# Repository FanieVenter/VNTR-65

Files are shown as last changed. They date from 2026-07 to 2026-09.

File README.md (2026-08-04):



# VNTR-65

A custom, over-engineered 65% keyboard featuring an RP2350 MCU, a hall effect key matrix, an analog slide potentiometer, and an OLED display. Built for daily use thanks to Hack Club.

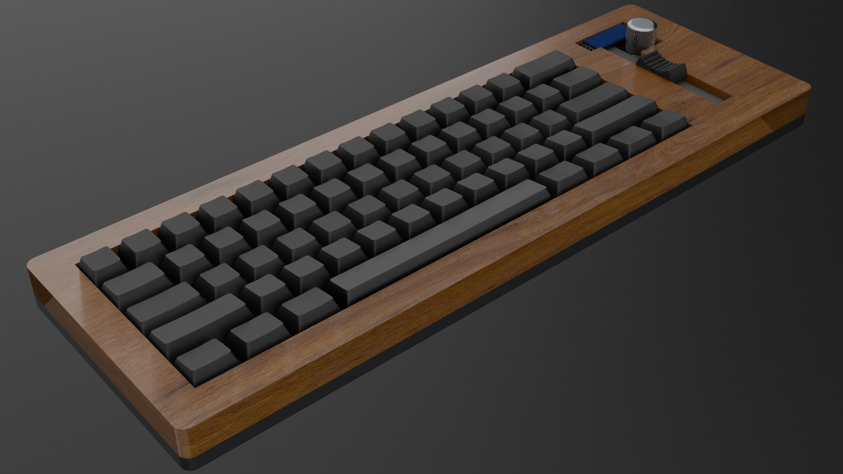
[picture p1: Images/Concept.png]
Concept Image


## Why I decided to make this keyboard.
I wanted to build a nice keyboard that I could use every day at school while knowing it won't break, I also wanted to make a keyboard that used hall effect switches to allow for analog inputs in racing ganes like Assetto Corsa and giving me a more challenging and fun experience designing it.

## How to use it.
To use this keyboard you will need to either download the production files for JLCPCB or create your own by exporting it them from Kicad. You will then need to place a order for the PCB using the productions files at your chosen pcb manufacturer. After you have received the PCB you will need to solder all the components onto the PCB and then flash the firmware onto the RP2350. While this is happening you can either 3d print the case or get it milled out of aluminum and wood. After you have the case and the PCB ready you can then assemble the keyboard and upload the firmware to the RP2350 and then you can use it. 

## What I learnt with this project.
I learn't how to design a keyboard from scratch using Kicad for the pcb. I also learn't how to use onshape after deciding to swap to it from Freecad a little bit because the projects says to have it in onshape but mostly as I had realised after 2 years of FreeCAD use that it wasn't powerful enough for me. I learn't how to take a raw wood texture file and make it look like a satin polyeuranted finished piece of wood in blender.
# Important.
The cost of the pcba has gone down since I submitted the project for review. For updated pricing and screenshot check the [BOM](BOM.pdf).

## Onshape Link
Onshape link for the [Case](https://cad.onshape.com/documents/299d1cd18e1c0fa7ad37c188/w/39af968ec4536d8e3dda6814/e/b83c5326b9acf81a68bd5a35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).

## Files
- [Journal](Journal.md) Journal of this project.
- [PCB Files](Hardware/PCB) Kicad files for the keyboard.
- [Production Files](Hardware/PCB/production) Production files for this project.
- [3D Files](Hardware/3D%20Models) 3D models used in this project as well as where the blender file is.
- [Gallery](Gallery.md) Images of the project and renders of the keyboard.
- [BOM (PDF)](BOM.pdf) Bill of materials.
- [BOM (CSV)](BOM.csv) Bill of materials in CSV format.

## Schematic-Main
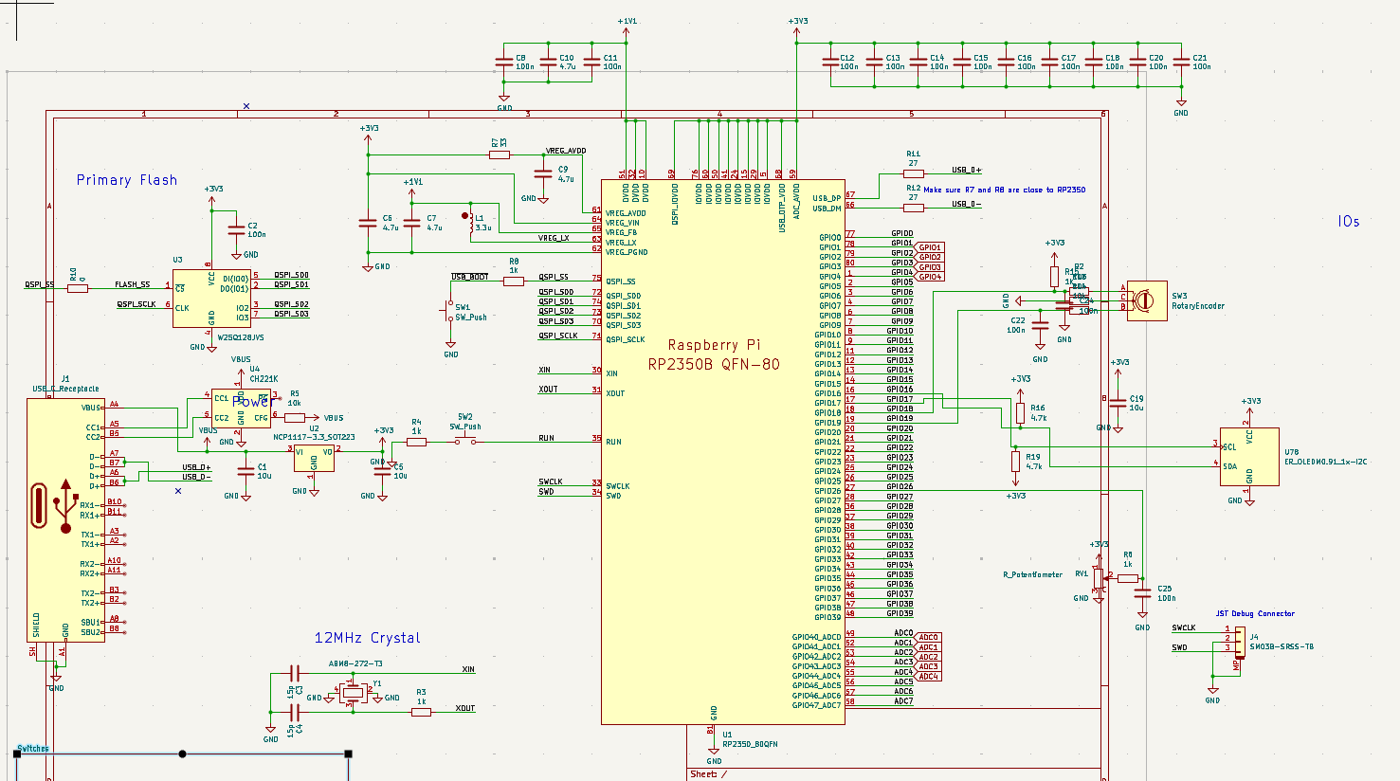
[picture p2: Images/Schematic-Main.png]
Schematic-Main


*Main schematic.*  

## Schematic-Switch
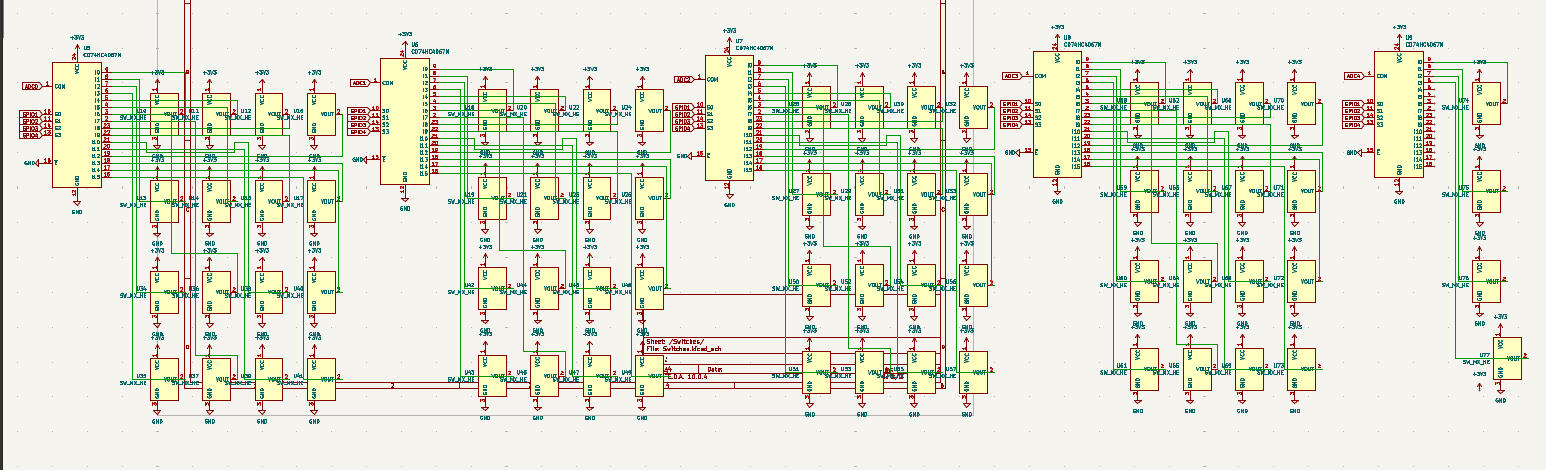
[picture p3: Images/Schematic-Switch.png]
Schematic-Switch


*Hall effect switch matrix.*

## PCB Photos
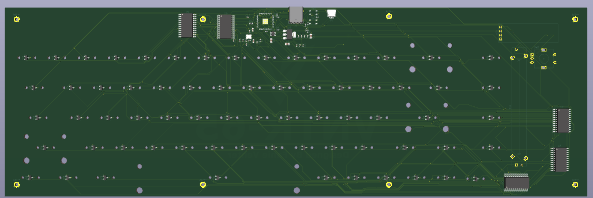
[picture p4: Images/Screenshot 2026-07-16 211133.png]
PCB Front

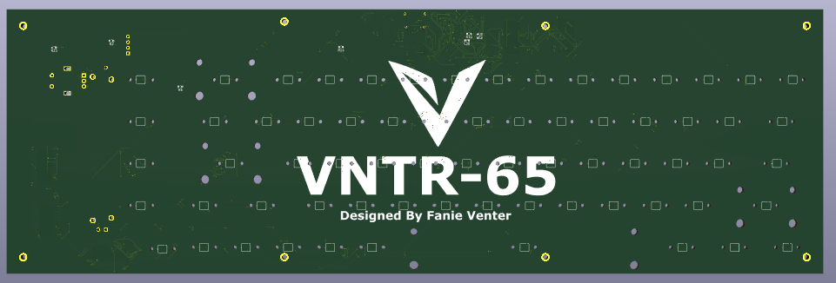
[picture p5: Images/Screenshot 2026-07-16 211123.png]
PCB Back (with silkscreen)


*Front and back of the PCB — the back has the silkscreen applied.*

## Wiring
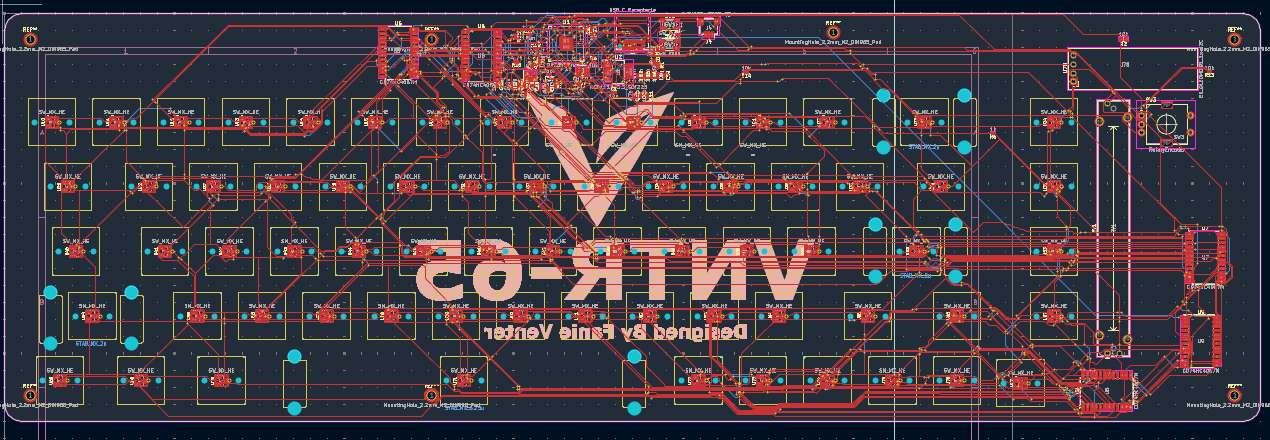
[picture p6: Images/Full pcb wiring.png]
Full PCB wiring


*Full PCB wiring across all copper layers.*

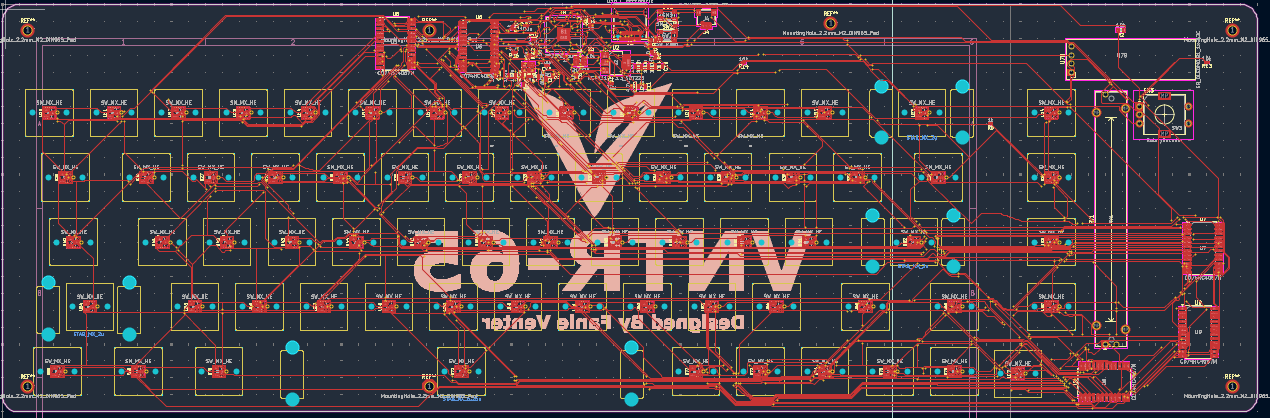
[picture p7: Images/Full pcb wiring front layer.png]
Full PCB wiring front layer


*Full PCB wiring on the front copper layer.*

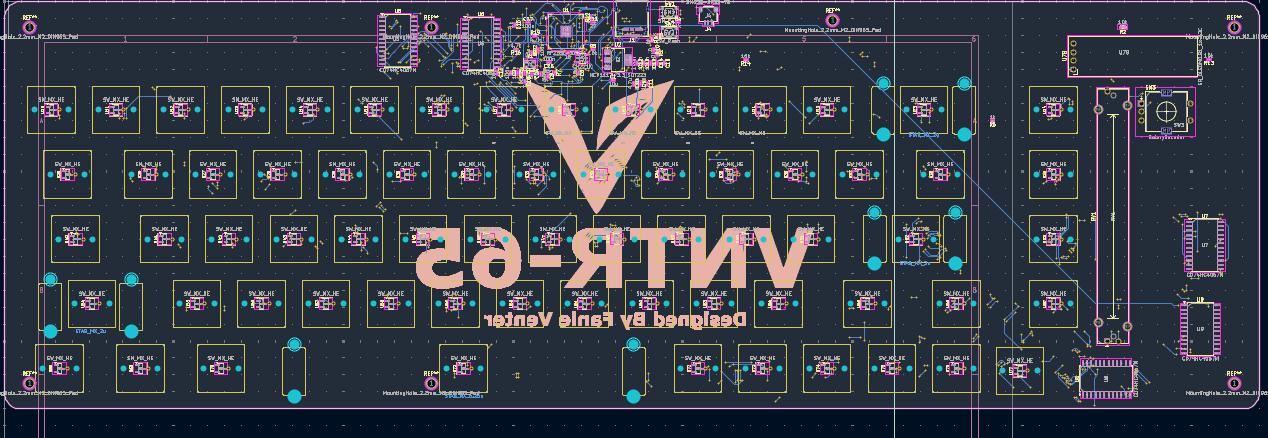
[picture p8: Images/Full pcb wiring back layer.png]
Full PCB wiring back layer


*Full PCB wiring on the back copper layer.*

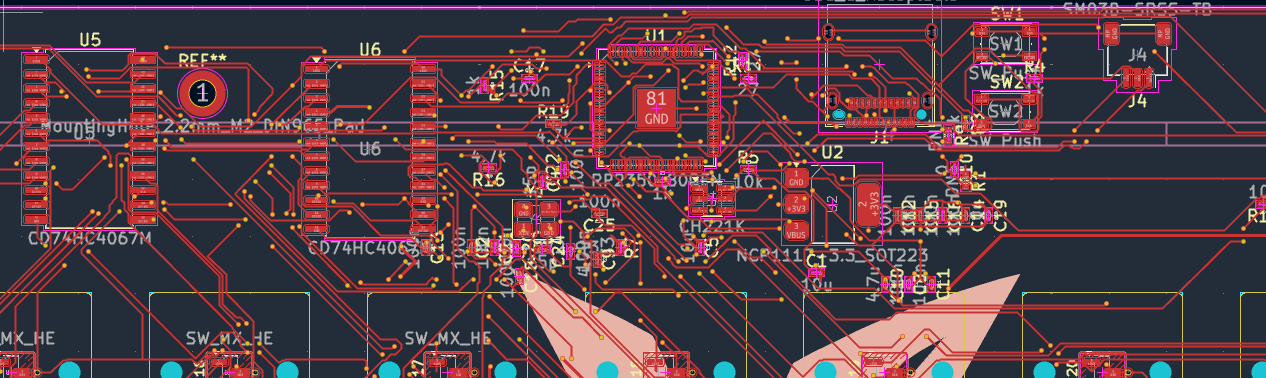
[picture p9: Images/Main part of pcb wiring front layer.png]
Main part of PCB wiring front layer


*Main section wiring on the front copper layer.*

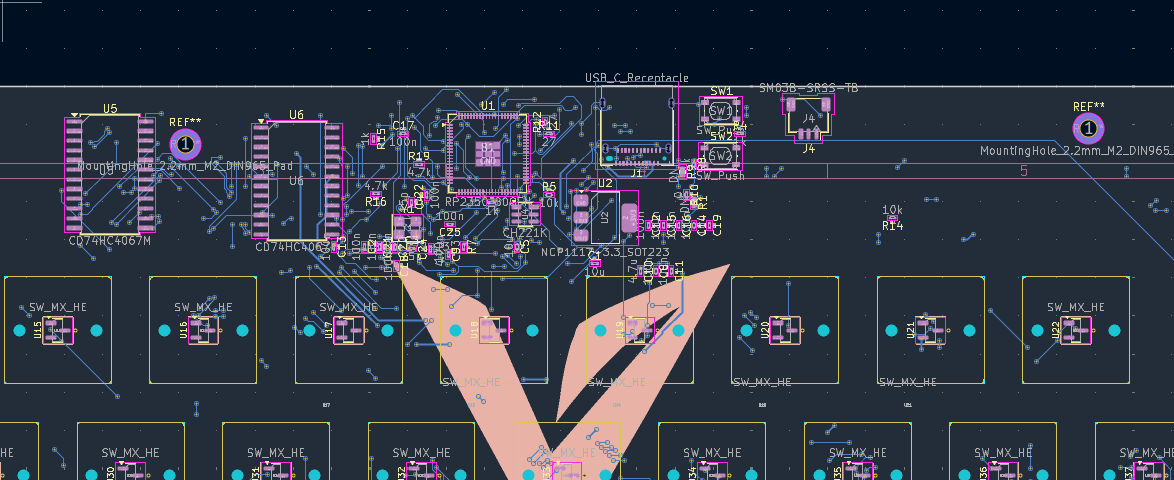
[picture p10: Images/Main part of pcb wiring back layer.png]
Main part of PCB wiring back layer


*Main section wiring on the back copper layer.*

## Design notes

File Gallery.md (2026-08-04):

# Gallery

## 2026-07-09

Keyboard Layout

*SVG layout showing the initial key positioning.*

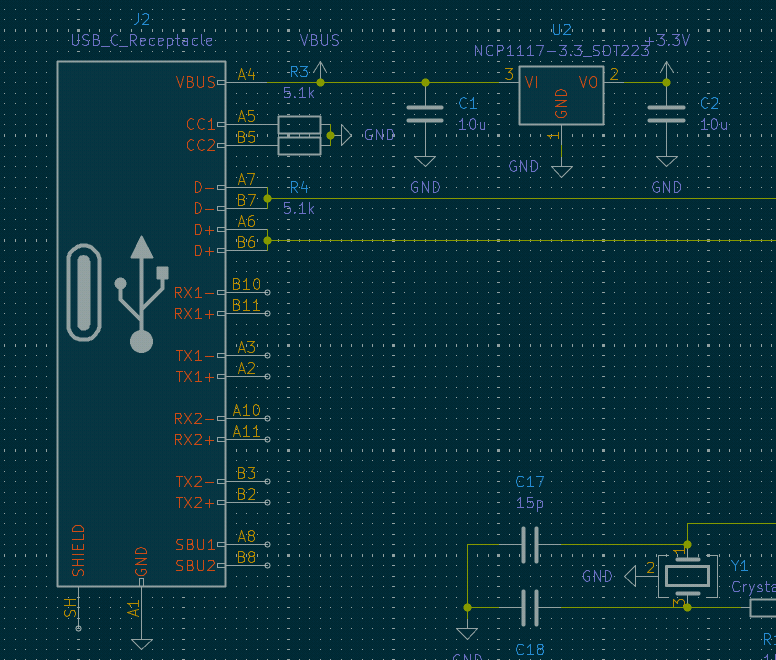
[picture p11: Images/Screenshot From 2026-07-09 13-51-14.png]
KiCad schematic at 13:51


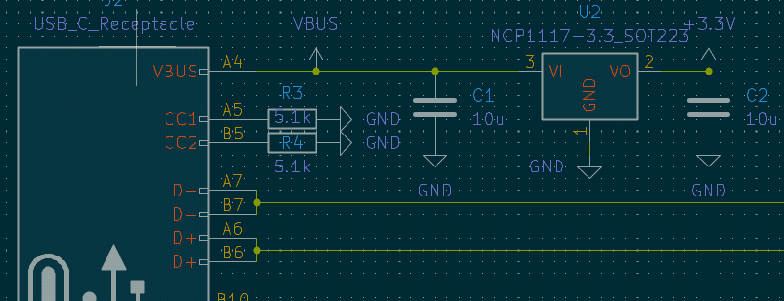
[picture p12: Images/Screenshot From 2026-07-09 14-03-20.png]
KiCad schematic at 14:03


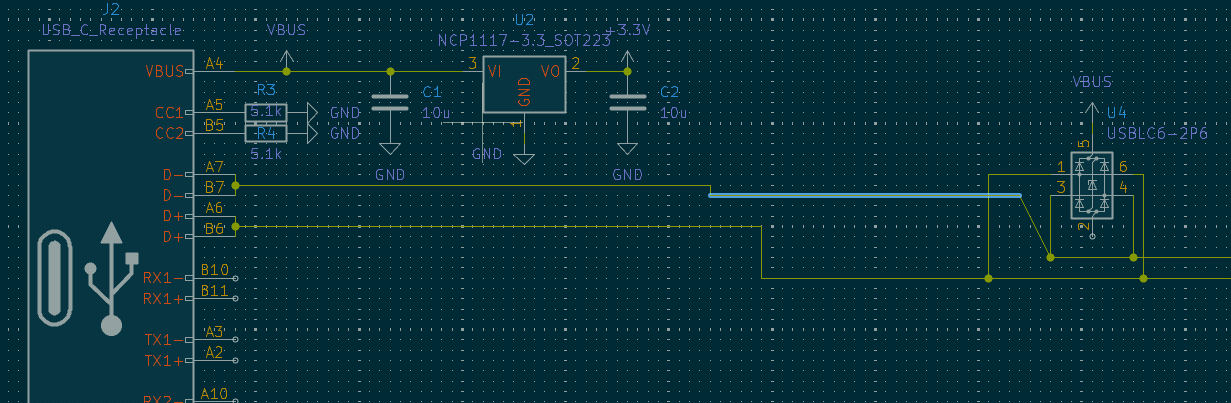
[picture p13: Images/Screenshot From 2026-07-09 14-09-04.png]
KiCad schematic at 14:09


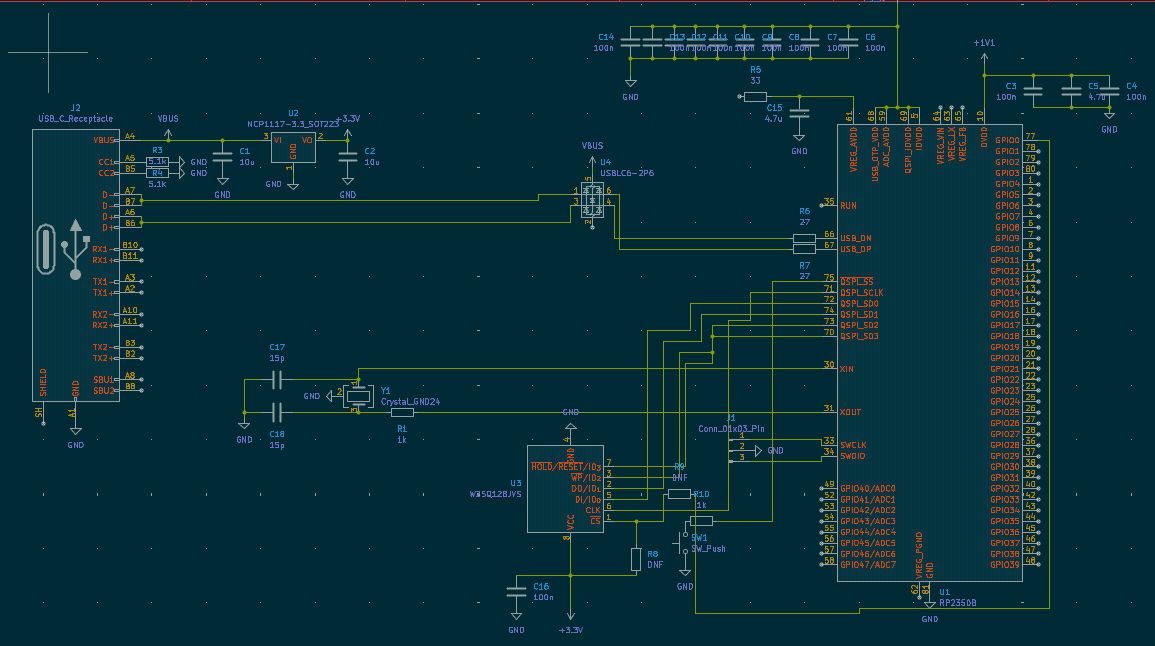
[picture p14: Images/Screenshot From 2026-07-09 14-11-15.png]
KiCad schematic at 14:11


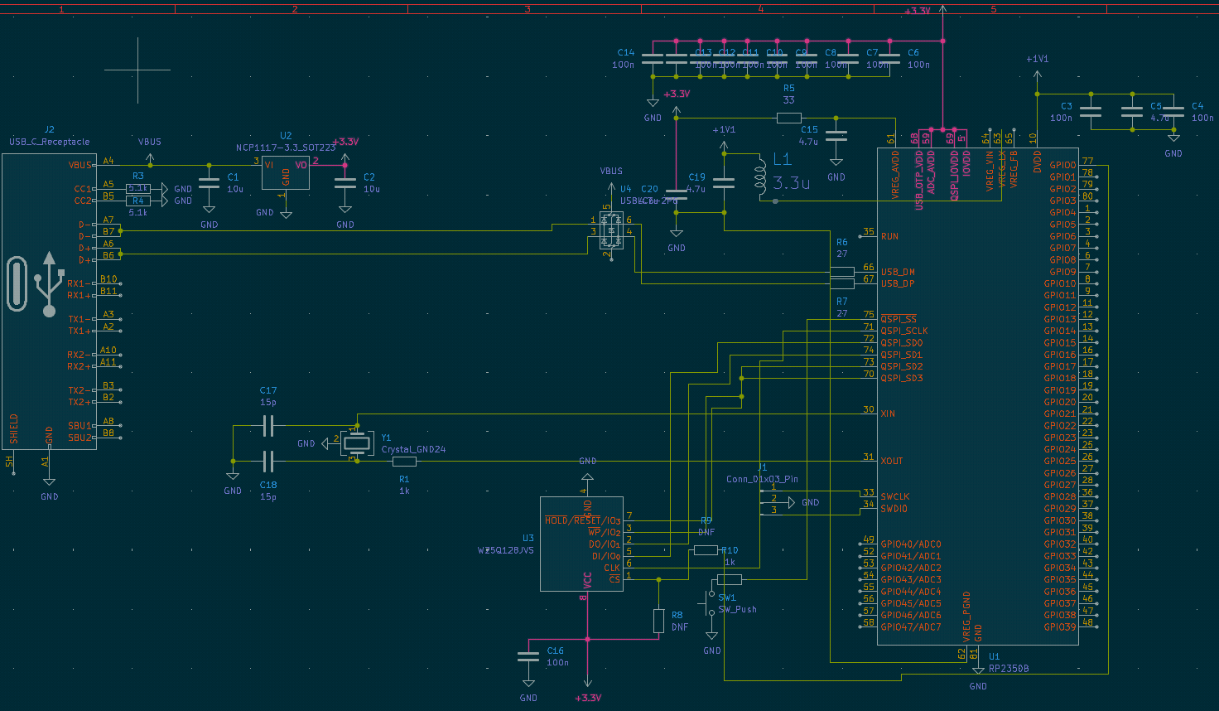
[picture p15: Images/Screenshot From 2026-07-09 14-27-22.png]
KiCad schematic at 14:27


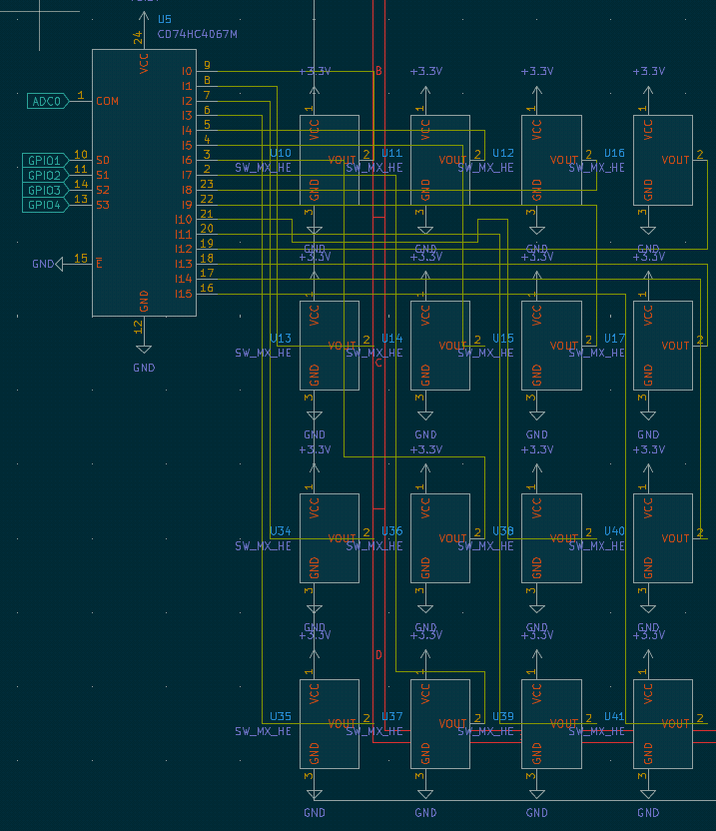
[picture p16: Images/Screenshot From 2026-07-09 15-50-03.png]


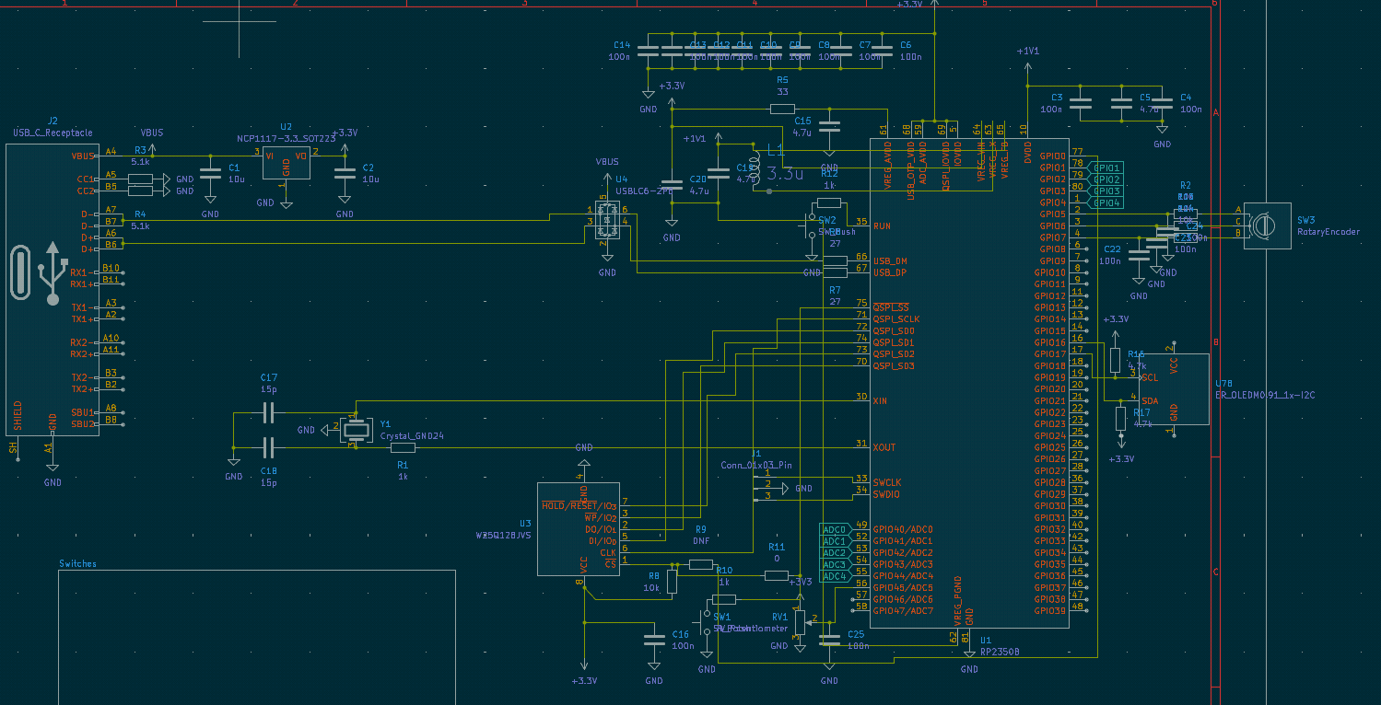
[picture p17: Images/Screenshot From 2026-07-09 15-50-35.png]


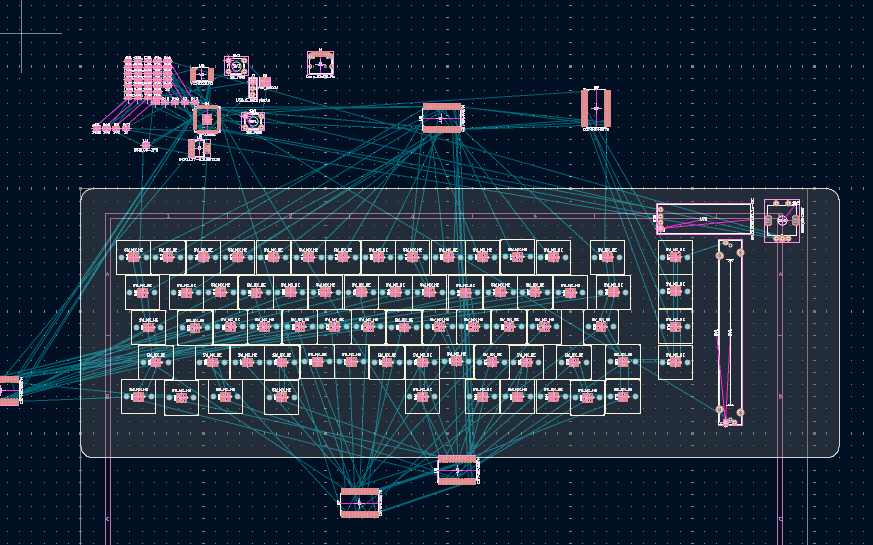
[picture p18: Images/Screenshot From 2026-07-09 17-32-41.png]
PCB layout at 17:32


*Schematic and PCB design progress from 9 July.*

## 2026-07-10

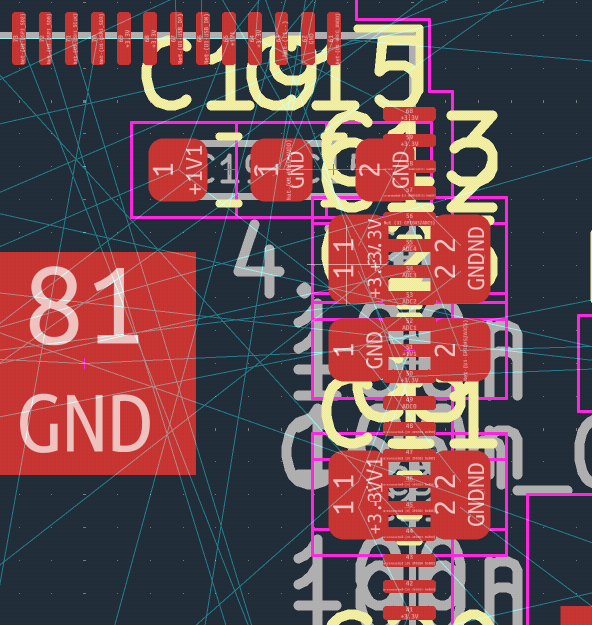
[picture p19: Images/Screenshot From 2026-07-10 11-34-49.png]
PCB routing at 11:34


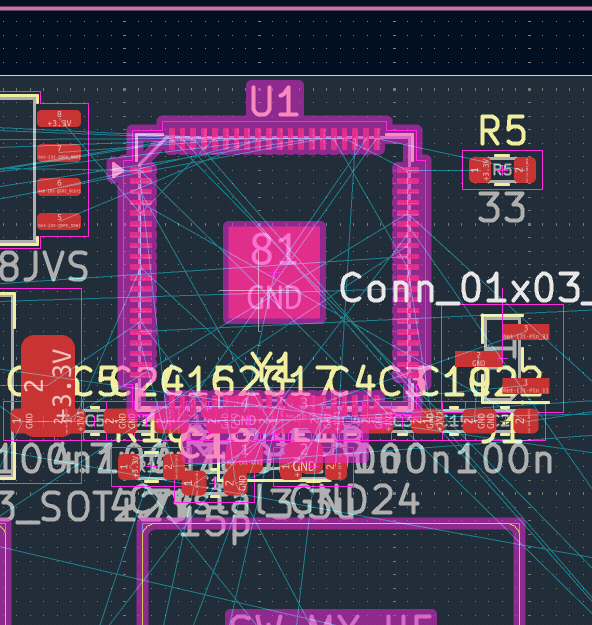
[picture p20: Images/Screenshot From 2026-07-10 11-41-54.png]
PCB routing at 11:41


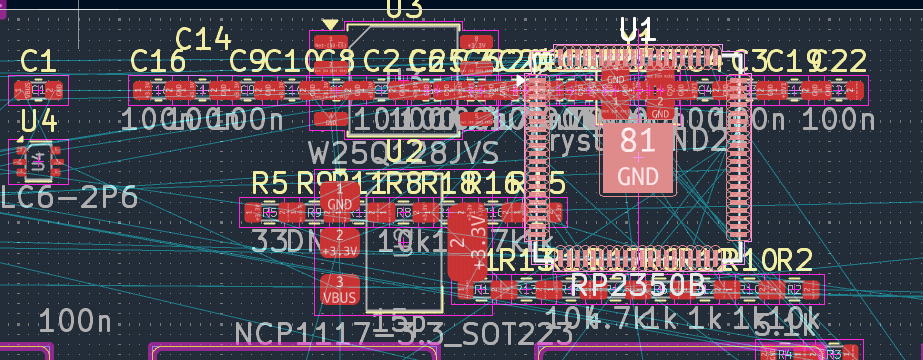
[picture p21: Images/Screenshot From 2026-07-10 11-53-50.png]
PCB routing at 11:53


*PCB routing and case design work from 10 July.*

## 2026-07-12

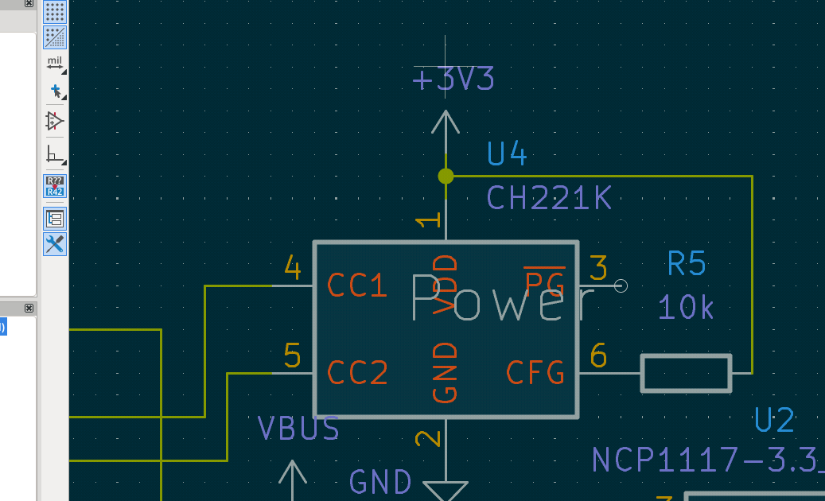
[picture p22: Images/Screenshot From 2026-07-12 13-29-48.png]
Rerouted PCB at 13:29


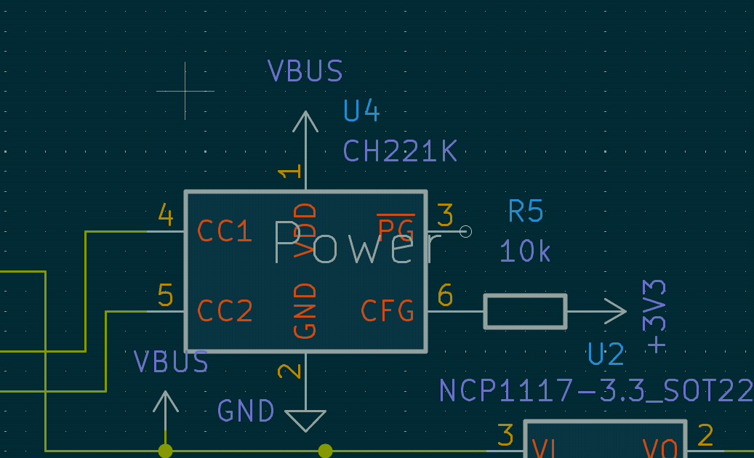
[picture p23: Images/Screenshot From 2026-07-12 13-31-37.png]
Rerouted PCB at 13:31


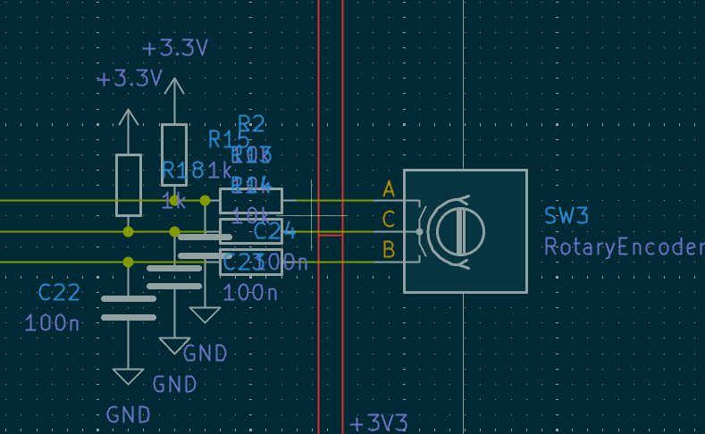
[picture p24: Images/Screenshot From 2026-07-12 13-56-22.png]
Rerouted PCB at 13:56


*Routing and layout refinements from 12 July.*

## 2026-07-15

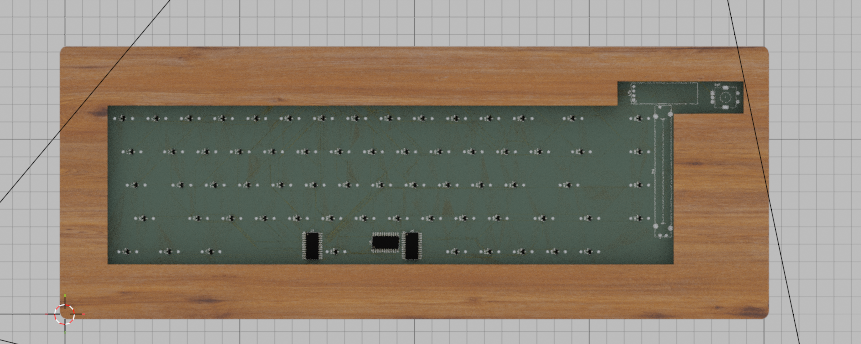
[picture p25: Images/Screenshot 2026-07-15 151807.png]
PCB Screenshot


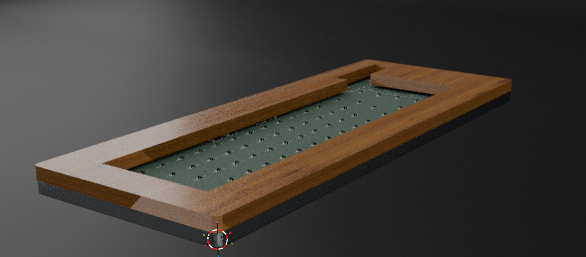
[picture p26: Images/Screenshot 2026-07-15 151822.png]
PCB Screenshot


*Blender screenshots from 15 July.*

## 2026-07-16

PCB Front

PCB Back (with silkscreen)

*PCB front and back (with silkscreen) from 16 July.*

Concept

*Full concept render of the keyboard case and PCB.*

## Wiring

Full PCB wiring

*Full PCB wiring across all copper layers.*

Full PCB wiring front layer

*Full PCB wiring on the front copper layer.*

Full PCB wiring back layer

*Full PCB wiring on the back copper layer.*

Main part of PCB wiring front layer

*Main section wiring on the front copper layer.*

Main part of PCB wiring back layer

*Main section wiring on the back copper layer.*

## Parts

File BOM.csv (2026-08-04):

SI No. | Name | Notes | Quantity | Price Per Unit | Cost | Total | Link
1 | Gateron White KS20 Hall Effect Switches | MX-compatible hall effect switches | 68 | 0.48 | 32.64 |  | https://geon.works/products/geon-raw-he-switch
2 | MDK ZDA thick black keycaps Keycap Set | 68-key keycap set for 65% layout | 1 | 20.3471296 | 20.3471296 |  | https://www.aliexpress.com/item/1005008792587187.html
3 | EC11 Rotary Encoder Knob | EC11 encoder Knob | 1 | 1 | 1 |  | https://keeb.io/products/rotary-encoder-knob-ec11?variant=16012055052382
4 | Slide Potentiometer Knob | Knob for Bourns PTA6043 | 1 | 1.7489024 | 1.7489024 |  | https://www.digikey.co.nz/en/products/detail/cliff-electronic-components-ltd/FC72621/21406847
5 | Stabilizer Set (65%) | Screw-in stabilizers: 1x 6.25u + 3x 2u | 1 | 16 | 16 |  | https://www.gateron.com/products/gateron-screw-in-stabilizer?VariantsId=10175
6 | M2x12mm Bolts | Pack of 20 for case assembly | 1 | 3.1163328 | 3.1163328 |  | https://www.aliexpress.com/item/1005004492454886.html
7 | M2x5mm Threaded Insert | Pack of 10 brass threaded inserts | 1 | 2.523584 | 2.523584 |  | https://www.aliexpress.com/item/1005002428162691.html
8 | EC11 Rotary Encoder | EC11E Rotary Encoder | 1 | 5.2936576 | 5.2936576 |  | https://www.digikey.co.nz/en/products/detail/alps-alpine/EC11E15244G1/21721550
9 | USB-C Cable | Data cable for connecting keyboard | 0 | 16.2683136 | 0 |  | https://www.aliexpress.com/item/1005009051714044.html
10 | 0.91" SSD1306 OLED Display | 0.91" SSD1306 OLED Display | 1 | 5.73 | 5.73 |  | https://www.aliexpress.com/item/1005004572487969.html
11 | PCB + PCBA (JLCPCB) | RP2350-based PCB with all SMD components assembled | 1 | 186.06 | 186.06 |  | https://jlcpcb.com
12 | Sliding Potientometer | PTA6043-2010CIB103 | 1 | 2.62 | 2.62 |  | https://www.digikey.co.nz/en/products/detail/bourns-inc/PTA6043-2010CIB103/3781224
13 | Case Manufacturing (Aluminum + Wood) | Custom milled case | 0 | 89.3 | 0 |  | https://jlccnc.com/
 |  |  |  |  |  | 277.0796064

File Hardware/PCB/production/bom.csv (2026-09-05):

Designator | Footprint | Quantity | Value | LCSC Part #
C1, C19, C5 | 0603 | 3 | 10u
C10, C6, C7, C9 | 0603 | 4 | 4.7u
C11, C12, C13, C14, C15, C16, C17, C18, C2, C20, C21, C22, C24, C25, C8 | 0603 | 15 | 100n
C3, C4 | 0603 | 2 | 15p
J1 | USB_C_Receptacle_Amphenol_12401610E4-2A | 1 | USB_C_Receptacle
J4 | JST_SH_SM03B-SRSS-TB_1x03-1MP_P1.00mm_Horizontal | 1 | A1002WR-S-3P | C239521
R1, R9 | 0402 | 2 | DNF
R10 | 0603 | 1 | 0
R11, R12 | 0603 | 2 | 27
R13, R14, R2, R5 | 0603 | 4 | 10k
R15, R3, R4, R6, R8 | 0603 | 5 | 1k
R16, R19 | 0603 | 2 | 4.7k
R7 | 0603 | 1 | 33
RV1 | Potentiometer_Bourns_PTA6043_Single_Slide | 1 | R_Potentiometer
SW1, SW2 | SW_Push_1P1T_NO_Vertical_Wuerth_434133025816 | 2 | SW_Push
SW3 | RotaryEncoder_Alps_EC11E-Switch_Vertical_H20mm | 1 | RotaryEncoder
U1 | QFN-80-1EP_10x10mm_P0.4mm_EP3.4x3.4mm | 1 | RP2350_80QFN
U10, U11, U12, U13, U14, U15, U16, U17, U18, U19, U20, U21, U22, U23, U24, U25, U26, U27, U28, U29, U30, U31, U32, U33, U34, U35, U36, U37, U38, U39, U40, U41, U42, U43, U44, U45, U46, U47, U48, U49, U50, U51, U52, U53, U54, U55, U56, U57, U58, U59, U60, U61, U62, U63, U64, U65, U66, U67, U68, U69, U70, U71, U72, U73, U74, U75, U76, U77 | SW_MX_HE_0deg_1u | 68 | SW_MX_HE
U2 | SOT-223-3_TabPin2 | 1 | NCP1117-3.3_SOT223
U3 | SOIC-8_3.9x4.9mm_P1.27mm | 1 | W25Q128JVS
U4 | SOT-23-6 | 1 | CH221K
U5, U6, U7, U8, U9 | SOIC-24W_7.5x15.4mm_P1.27mm | 5 | CD74HC4067M
U78 | ER_OLEDM0.91_1x-I2C | 1 | ER_OLEDM0.91_1x-I2C
Y1 | Crystal_SMD_3225-4Pin_3.2x2.5mm | 1 | ABM8-272-T3

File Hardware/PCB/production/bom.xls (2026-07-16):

Comment | topDesignator | bottomDesignator | Footprint | JLCPCB Part #
100n |  |  | 0603 | C14663
33 |  |  | 0402 | C25105
NCP1117-3.3_SOT223 |  |  | SOT-223-3_TabPin2 | C26537
RP2350_80QFN |  |  | QFN-80-1EP_10x10mm_P0.4mm_EP3.4x3.4mm | C42415655
27 |  |  | 0402 | C1152
SW_MX_HE |  |  | SW_MX_HE_0deg_1u | C19089525
R_Potentiometer |  |  | Potentiometer_Bourns_PTA6043_Single_Slide | C17237498
CH221K |  |  | SOT-23-6 | C5125736
1k |  |  | 0603 | C14676
RotaryEncoder |  |  | RotaryEncoder_Alps_EC11E-Switch_Vertical_H20mm | C19712528
4.7u |  |  | 0402 | C23733
SW_Push |  |  | SW_Push_1P1T_NO_Vertical_Wuerth_434133025816 | C2939606
10k |  |  | 0402 | C60490
15p |  |  | 0402 | C1548
CD74HC4067M |  |  | SOIC-24W_7.5x15.4mm_P1.27mm | C1545936
SM03B-SRSS-TB |  |  | JST_SH_SM03B-SRSS-TB_1x03-1MP_P1.00mm_Horizontal | C160403
1k |  |  | 0402 | C11702
ABM8-272-T3 |  |  | Crystal_SMD_3225-4Pin_3.2x2.5mm | C20625731
4.7k |  |  | 0603 | C23162
10u |  |  | 0805 | C440198
100n |  |  | 0402 | C1525
0 |  |  | 0402 | C17168
USB_C_Receptacle |  |  | USB_C_Receptacle_Amphenol_12401610E4-2A | C129018
10k |  |  | 0603 | C15401

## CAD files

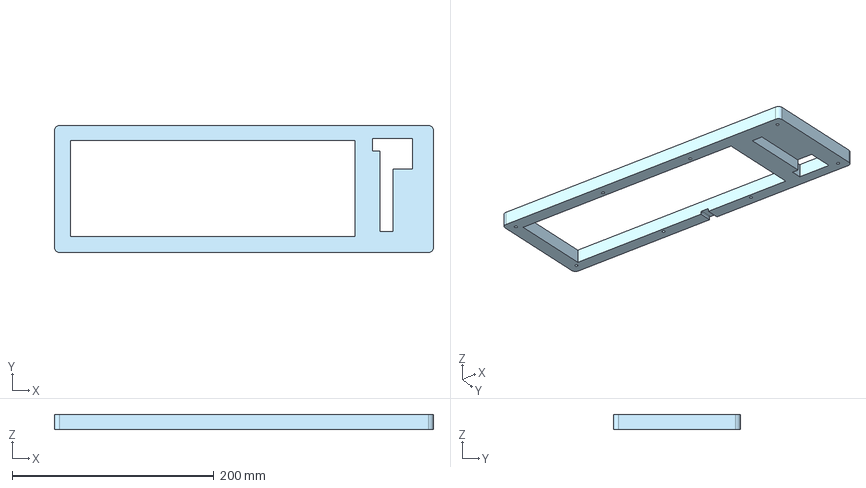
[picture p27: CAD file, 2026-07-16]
Hardware/3D Models/Case/VNTR-65-Case-Wood.step
376.0 x 126.0 x 15.0 mm

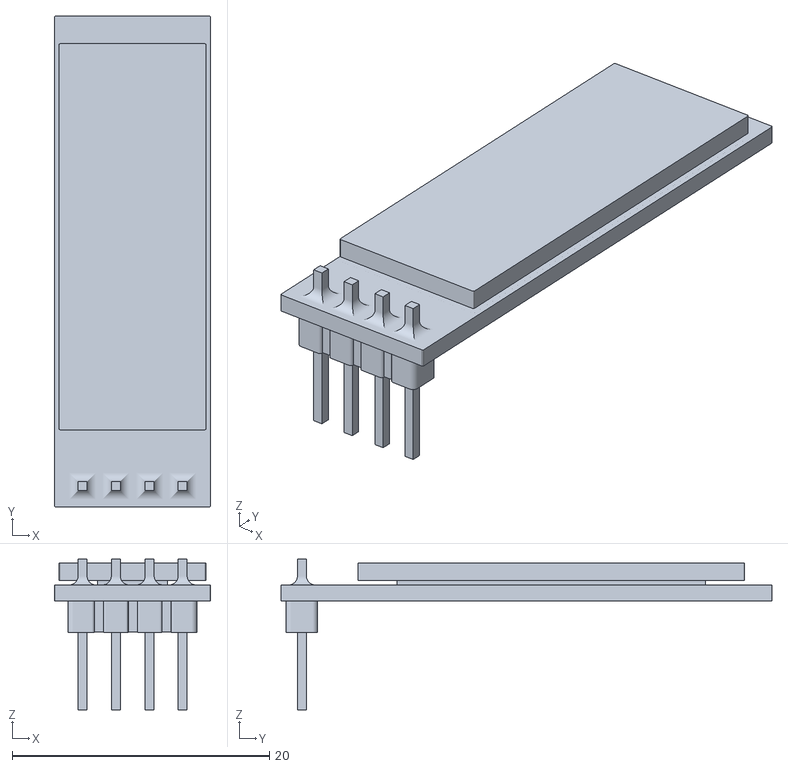
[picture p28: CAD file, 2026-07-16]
Hardware/3D Models/Components/ssd1306-0-91.stl
12.1 x 38.2 x 11.7

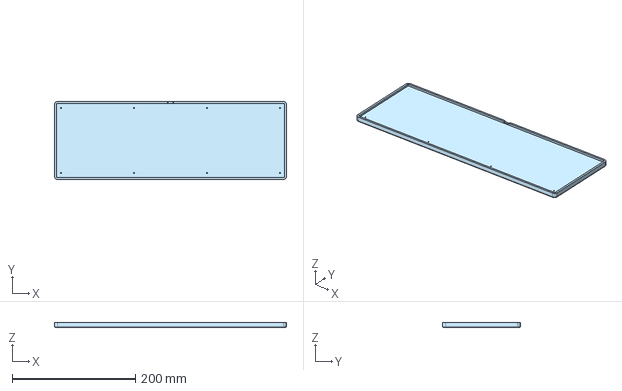
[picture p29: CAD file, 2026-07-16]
Hardware/3D Models/Case/VNTR-65-Case-Aluminum.step
376.0 x 126.0 x 8.00 mm

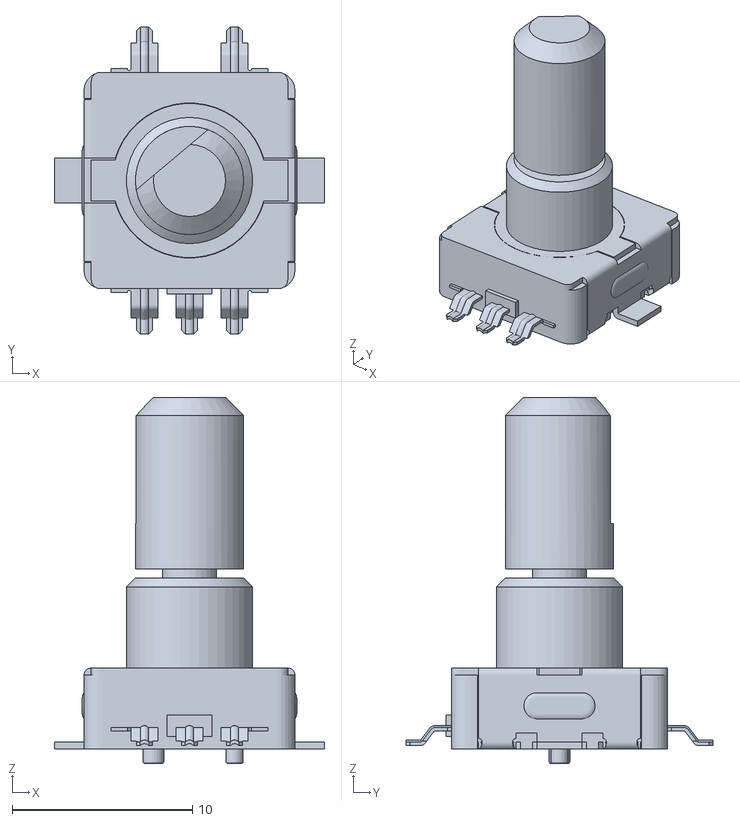
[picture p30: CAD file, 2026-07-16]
Hardware/3D Models/Components/EC11.stl
15.0 x 17.0 x 20.3

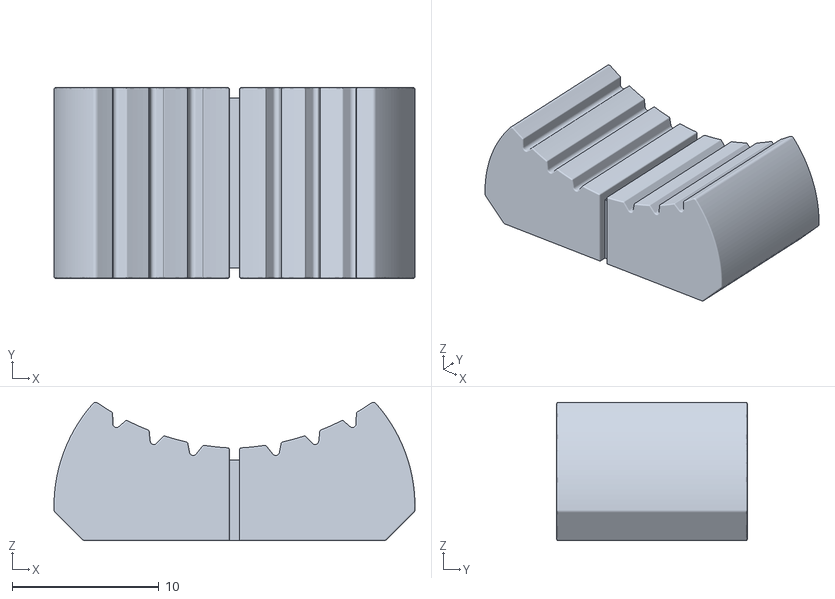
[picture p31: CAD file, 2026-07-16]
Hardware/3D Models/Components/faderKnob.stl
24.6 x 13.0 x 9.42

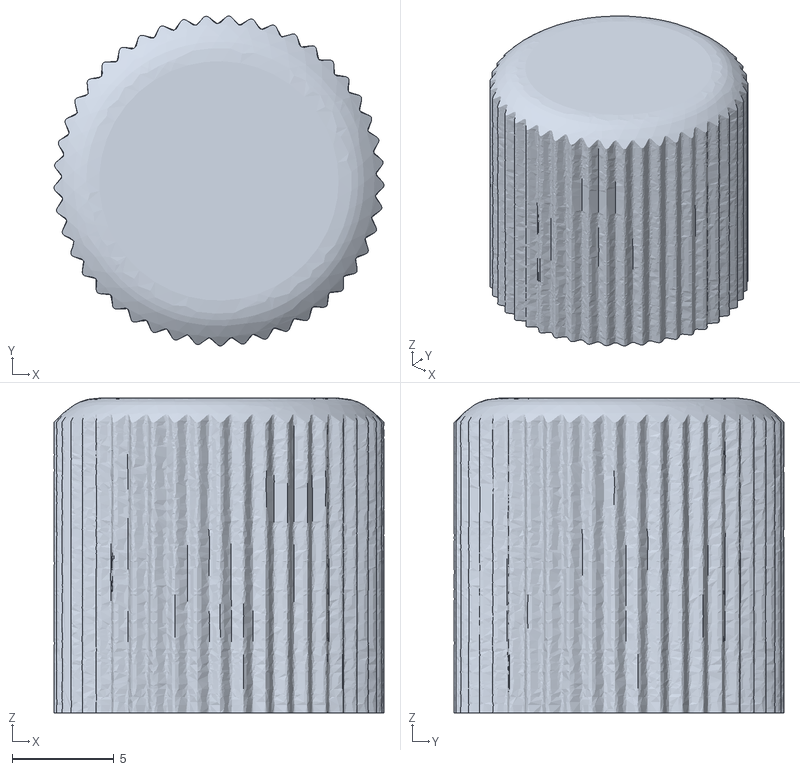
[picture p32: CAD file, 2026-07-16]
Hardware/3D Models/Components/Ec11 Knob.stl
16.3 x 16.2 x 15.5

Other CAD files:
Hardware/3D Models/Case/VNTR-65-Case-Aluminum.stl
Hardware/3D Models/Case/VNTR-65-Case-Wood.stl

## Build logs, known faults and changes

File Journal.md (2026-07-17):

# Journal
## July 8, 2026
### 8:00 - 8:30
Today I defined the specs for the project which is going to be a 65 percent keyboard with optical Gateron KS-22 Blacks, it will have a rotary encoder as well as a sliding pot for volume control, it will be wired and use Vial for firmware and have per-key RGB and use an RP2040. It will have PBT DSA keycaps and it will have an OLED screen on it, it is wired through USB-C, and I created the GitHub repo.
### 11:00 - 12:30
Decided to swap to hall effect for more wide support and custom actuation points. I decided to swap to Gateron Jade Pro (ks20) with PBT MT3 keycaps for a nice thocky sound. and I will have a vibration motor to allow for key press feedback and now using a RP2350 for better performance 
## Jul 9
### 11:20 - 11:45
I decided to move to a STM32F405RGT6 for better performance and better firmware compatibility.
### 11:40 - 11:45
I decided to move back to the RP2350 due to community support for the chips and better documentations.
### 16:00 - 18:00
I finished designing the first verion of the schematic and made a basic pcb with all the multiplexers having their buttons grouped with them.
## Jul 10
### 10:00 - 10:30
I refactored the repository so that everything is organised nicely and in its own folder.
### 11:00 - 19:00
I went through and configured the pcb as well as routing and started working on the case in onshape.
## Jul 12
### 11:00 - 17:00
I moved over to using the hardware design schematic for the RP2350b's minimalist schematic to make sure that the chip would boot instead of anyways trying to copy each component by hand. I also rerouted and placed everything on the pcb so that now everything is better routed.
## Jul 14
### 10:00 - 17:00
I worked on the case. I also added a few more mounting holes for the case. I also got the quote for the rough case outline and it would cost 117 USD for the case before shipping I also got the quote for the pcb and it would be 143 usd for just the pcb and 217 usd for the pcba maiking it 430 usd after shipping.
## Jul 15
### 11:00 - 11:15
I refined the pcb overall and made it a bit better and made sure to check over everything as well as moving all +3.3v nets to the +3v3 net. I also decided to remove the haptic feedback idea as that just overcomplicates things.
### 13:00 - 15:00
I reduced the size of the case so that it only weighs about 1kg now and I also made it so that it cost 80 usd instead of 127 as before, I made a blender file with all the parts and added a procedural texture for the aluminum. I also added a usb c cutout in the aluminum. I also added a threads drawing so that they will know where the threads go instead of guessing.
## Jul 16
### 10:00 - 15:00
I made the case sizing be appropriate and made the wood part of the case in onshape, I added both of those to the repo. I also refined the sizing of the pcb and moved the rotary encoder to a better spot. I added the ec11 rotary encoder as well as a knob for it to the blender file. I added the ssd1306 0.91 inch display to the blender file as well as a knob for the pta6043 as I couldnt find a model for the actual sliding pot. I also rendered a somewhat finilazed version of the keyboard and added it to the images folder as well as replacing the ai one in the readme
### 15:00 - 21:00
I have refined the journal and the project setup to be more complient/in line with what the keeb docs expect including adding more screenshots and images to the gallery adding the hours i worked in the journal and adding a BOM in both PDF and CSV format. I also added a concept image to the readme as well as a logo for the project. Updated the Threads drawing. Created a new render of the keyboard with the updated pcb after moving the usb c port so that its centered. I also created a logo for the project and added it to the readme. I also created a silkscreen graphic and added it to the pcb. I might also engrave it in the case.
## Jul 17
### 10:00 - 16:00
I sent the project in for review and edited the readme a bit to look better. I also reduced cost of pcb down to 235 usd total including pcba.

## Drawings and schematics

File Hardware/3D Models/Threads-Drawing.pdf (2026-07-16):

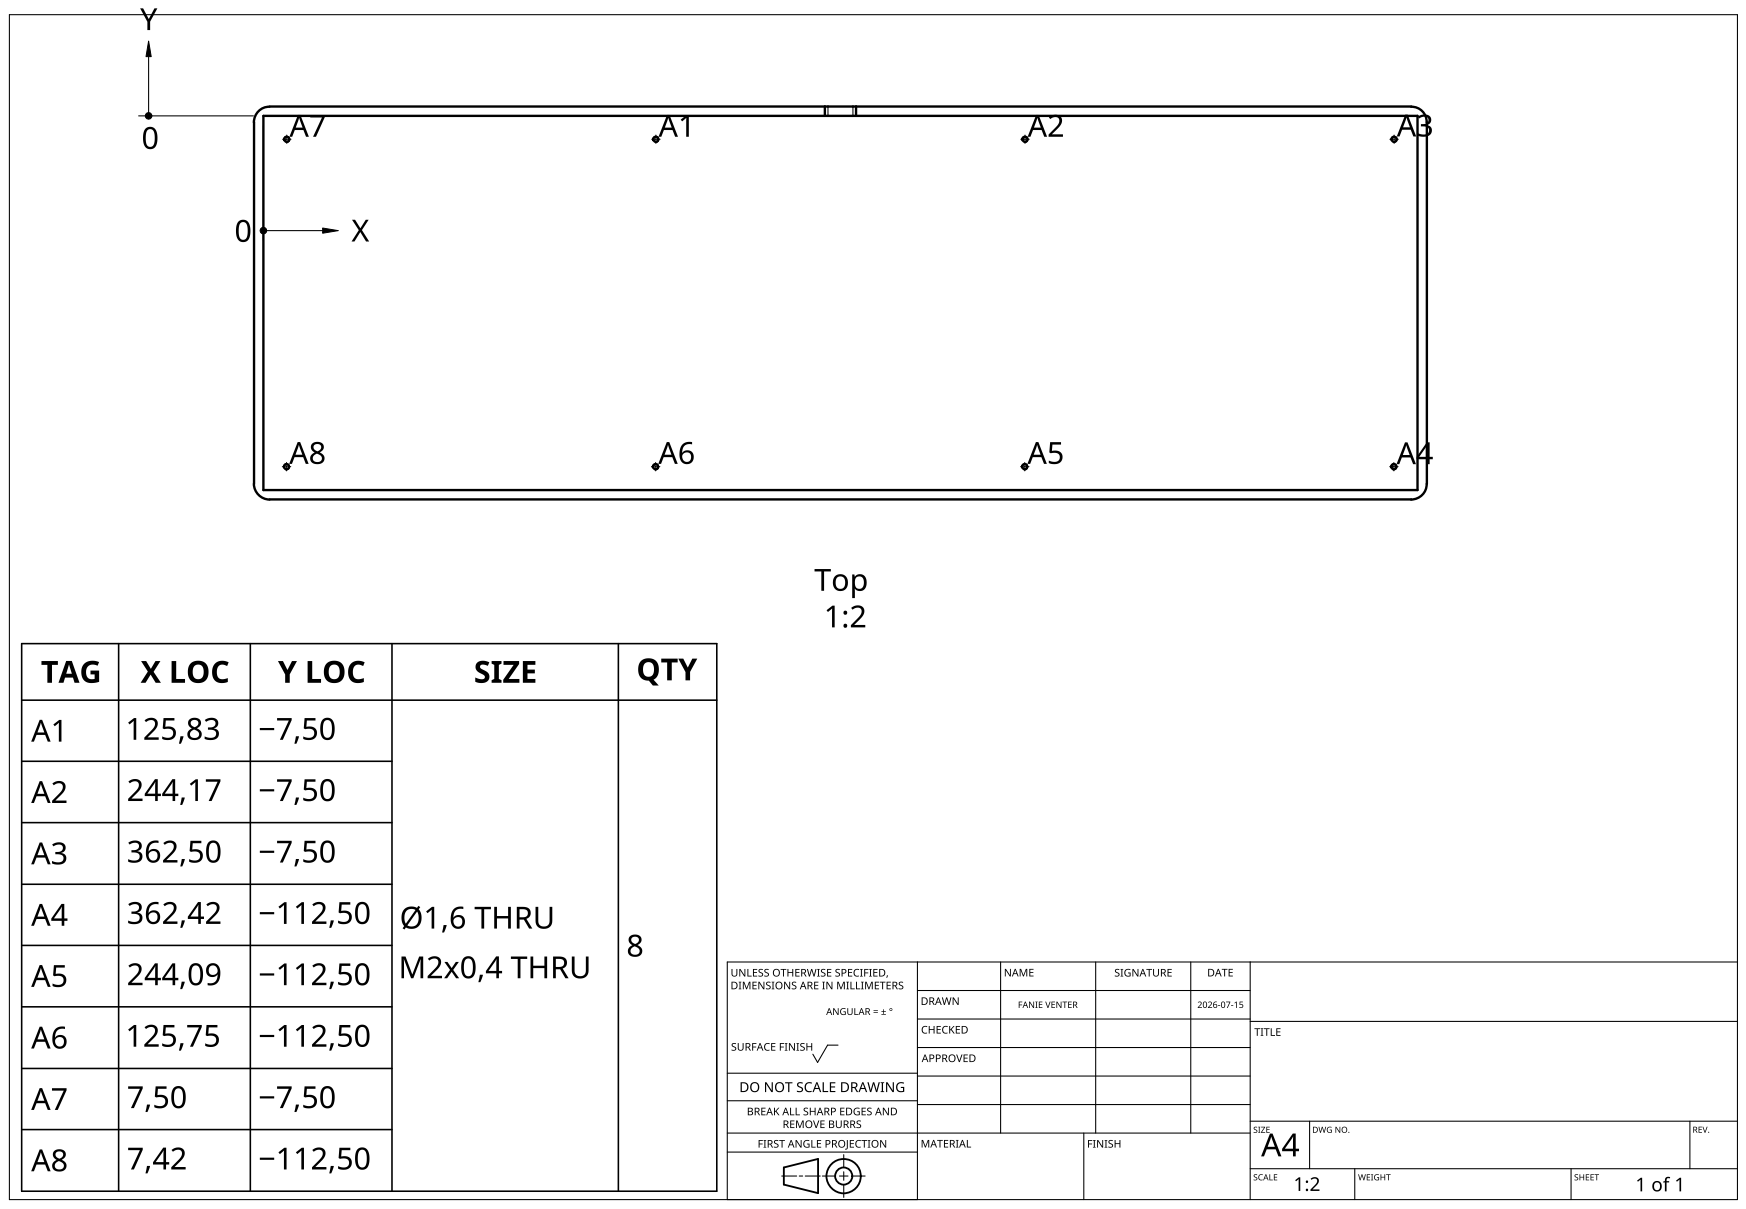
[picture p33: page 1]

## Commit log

2026-07-07 Update README.md to hall effect instead of optical
2026-07-07 Update journal to show decision to move from optical to hall effect for custom actuation points
2026-07-08 Change MCU from RP2350 to STM32F405RGT6
    Updated the MCU specification from RP2350 to STM32F405RGT6.
2026-07-09 Created Basic Functional Schematic with all needed features and created basic pcb with each multiplexer having its keys grouped with it
    [Switches.kicad_sch, Usb.kicad_sch, VNTR-65.kicad_pcb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]
2026-07-09 Assigned footprints to everything
    [VNTR-65.kicad_pcb, VNTR-65.kicad_sch]
2026-07-09 Positioned all the keys
    [VNTR-65.kicad_pcb]
2026-07-09 fix switch rotation
    [VNTR-65.kicad_pcb]
2026-07-09 moved components onto pcb and added pcb edge cut
    [VNTR-65.kicad_pcb, VNTR-65.kicad_sch]
2026-07-09 Moved all pcb files into a dedicated folder.
    [Switches.kicad_sch, Usb.kicad_sch, VNTR-65.kicad_pcb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]
2026-07-09 Use KBPlacer to place keys in correct positions
    [VNTR-65.kicad_pcb]
2026-07-10 Worked on organising pcb
    [VNTR-65.kicad_pcb]
2026-07-10 Routed PCB
    [VNTR-65.kicad_pcb, VNTR-65.kicad_sch]
2026-07-10 Generate Bom and gerber
    [VNTR-65.kicad_pcb]
2026-07-10 Added Mounting Holes
    [VNTR-65.kicad_pcb]
2026-07-10 Added Case
2026-07-12 Updated to rp2350 to a version of the minimal base schematic
    [VNTR-65.kicad_pcb, VNTR-65.kicad_sch]
2026-07-12 Connected everything with the new rp2350 setup
    [Switches.kicad_sch, VNTR-65.kicad_sch]
2026-07-12 Generated new gerber
2026-07-14 added more mounting holes
    [VNTR-65.kicad_pcb]
2026-07-14 added Step of pcb
    [PCB.step]
2026-07-14 Refined the pcb design overall
    [Switches.kicad_sch, VNTR-65.kicad_pcb, VNTR-65.kicad_sch]
2026-07-15 Reduced case volume and centered USB-C on PCB
    [Case-Aluminum.step, PCB.step, VNTR-65.kicad_pcb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]
2026-07-15 Added Threads Drawing
2026-07-15 Added Wood Part of the case to the blender model as well as trimming down the size of everything to a better looking proportion of 380mm by 125mm instead of 406 by 156mm.
    [Gateron KS-20 Magnetic Hall Sensor Switch KS-20T-20210922.stl, Gateron KS-20 Magnetic Hall Sensor Switch KS-20T-20210922.stp]
2026-07-15 Update pcb to smaller size
    [Switches.kicad_sch, VNTR-65.kicad_pcb]
2026-07-15 updated to smaller version of the case that only cost 76 usd
    [Case-Aluminum.step]
2026-07-16 Reorganised the whole 3d models folder and also redid the case sizing
    I redid the case sizing so that now it fits the desired size and will
    feel more comfortable to use, I made the wood part of the case in
    onshape and added it in to the blender file, I redid the sizing of the
    pcb so that it looks right, I added in the ec11 encoder the .91' screen
    and a knob for the sliding pot as I couldnt get the actual sliding pot
    schematic.
    [Case-Aluminum.step, EC11.stl, Ec11 Knob.stl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]
2026-07-16 renamed journal.md to Journal.md and added photo gallery in gallery.md
    Added photo gallery as keeb docs say to have a good amount of photos of
    the design. Note that There are still more screenshots to be added they
    are just currently on a diffrent machine
2026-07-16 Added times to journal.md and added step versions of case files as required in the keeb docs
    [VNTR-65-Case-Aluminum.step, VNTR-65-Case-Wood.step]
2026-07-16 Reroute the whole pcb so that it works for the new sizing and added in stabilizers
    [VNTR-65.kicad_pcb, bom.csv, designators.csv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]
2026-07-16 Added Bom and Updated Threads Drawing
2026-07-16 Added CSV Version of the bom
    [BOM.csv]
2026-07-16 Updated pcb so that the usb c port isnt 5mm of being centered
    [VNTR-65.kicad_pcb]
2026-07-16 Update Concept image with the new pcb routing
2026-07-16 Update blender file so that it has the new routing of the pcb
2026-07-16 Added JLC Bom with all correct parts
    [bom.csv, bom.xls]
2026-07-16 Created New Gerber
    [VNTR-65.kicad_pcb, positions.csv]
2026-07-16 Added Bom.csv to prod files
    [bom.csv]
2026-07-16 Added Logo and Silkscreen files
2026-07-16 Added Silkscreen to the pcb
2026-07-16 Added Screenshots of the updated pcb
2026-07-16 Added Updated Gerber
2026-07-17 Added photos schematic to the readme
2026-07-17 Moved Schematic around a bit so that it fits into screen better
    [Switches.kicad_sch, VNTR-65.kicad_sch]
2026-07-17 Rounded the corners of the pcb
2026-07-17 Removed components on the back to allow for economic pcba which will significantly reduce pcba costs
    [positions.csv]
2026-07-17 Updated bom to include new pricing using economic pcba
    [BOM.csv]
2026-08-04 Update PCB So that it is only 2 layers and that the smd components are standardized size(0603) this reduces pcb cost 186 to and overall cost to 277
    [VNTR-65.kicad_pcb, VNTR-65.kicad_sch, bom.csv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]
2026-08-04 Update boms
    [BOM.csv]
2026-08-04 Add wiring images
2026-08-27 Updated pcb
    [VNTR-65.kicad_pcb, VNTR-65.kicad_sch, bom.csv]
2026-08-27 Fix case sensitivity: Journal.md
2026-09-05 Routed U3
    [VNTR-65.kicad_pcb]
2026-09-05 Updated vais so that they are .2mm and 0.45mm not 0.4mm
    [VNTR-65.kicad_sch, bom.csv, designators.csv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]
